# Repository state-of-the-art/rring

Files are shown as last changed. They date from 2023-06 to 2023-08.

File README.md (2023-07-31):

# RRing

Smart-Ring opensource project

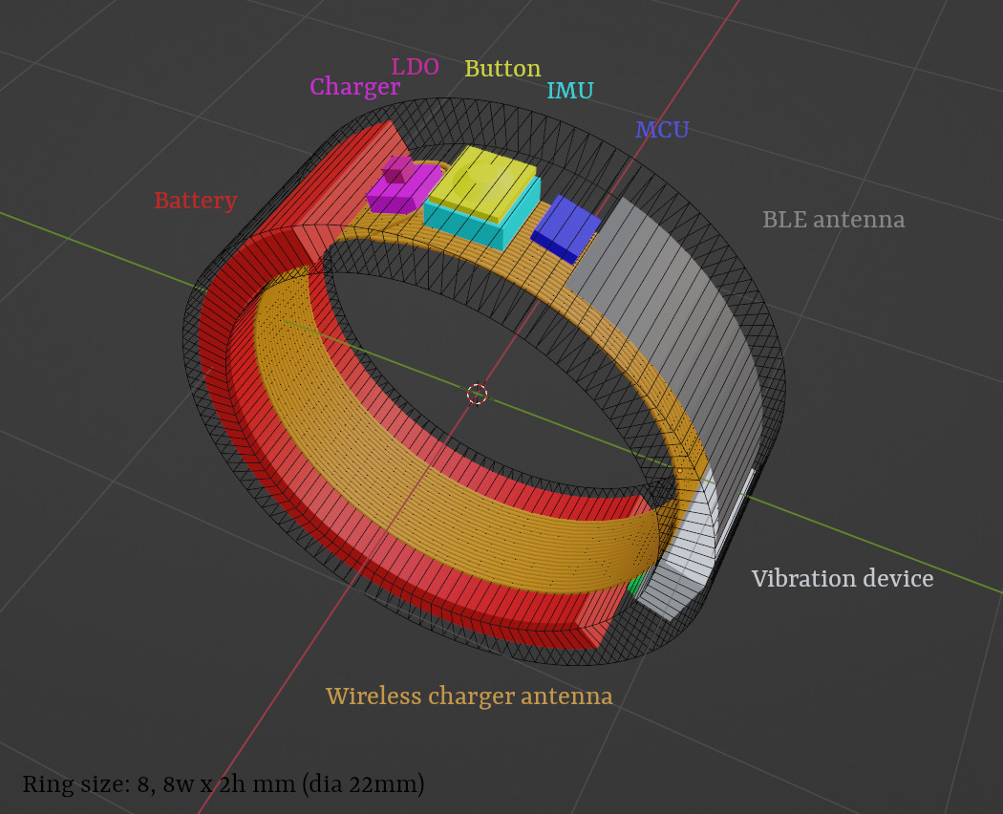
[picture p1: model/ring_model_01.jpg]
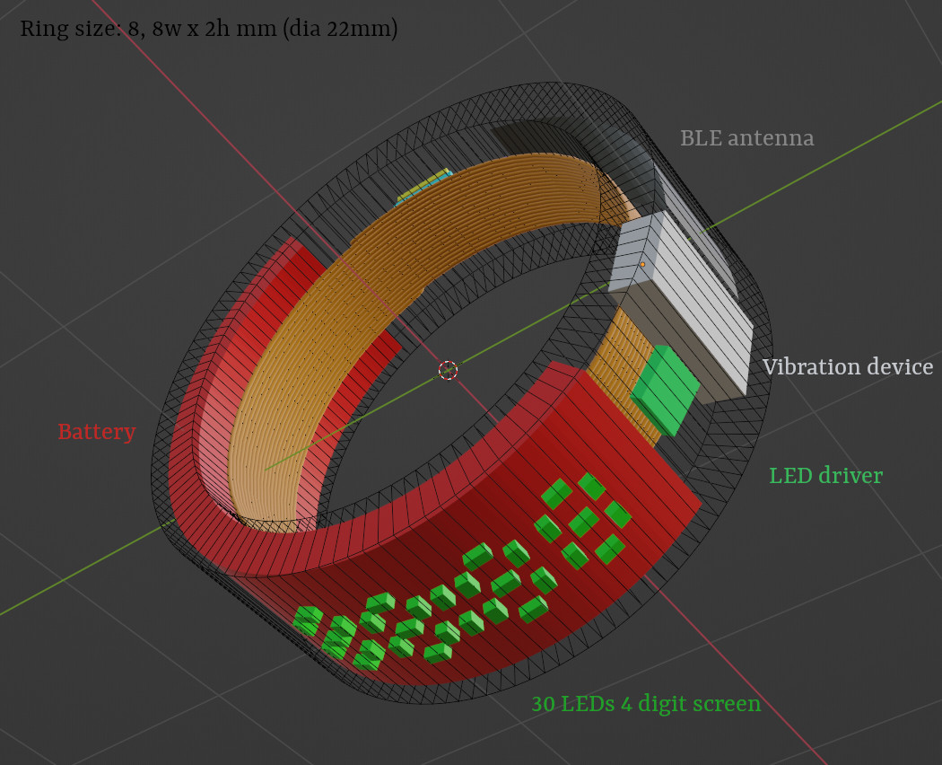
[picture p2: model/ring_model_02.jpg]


## Features

* BLE connection to smartphone
* Programmable button
* Integrated IMU for positioning in space (3d mouse)
* Show clock on little led display
* Silent vibro alarm, notifications and feedback
* Wireless charging

## BOM

* SOC:
   * MCU: DA14531-OG2 (WLCSP 17)
   * BT Antenna: ANT3216LL00R2400A (SMD Chip)
* Power:
   * Wireless charger: LTC4124 (LQFN 12)
   * Wireless charger antenna: ???
   * LDO: ADP160ACBZ-1.8-R7 (WLCSP 4)
   * Battery: ??? TODO ??? Curved, Li, ~7x33x17.7mm
* Clock display:
   * 4 digit 7 segment LED driver: TCA6418EYFPR (DSBGA 25)
   * 30 LEDs: IN-S21AT (0201)
* Control:
   * Button: KMT071NGJLHS (IP68)
   * IMU: ICM-20948 (QFN 24)
* Additional:
   * Vibro feedback: [EM custom](models/vibro_device-mk1.blend)

## Development

For PoC I used DA14531-00FXDEVKT-U (UM-B-125) - which is a small usb devboard with embedded debug
chip (uart/jtag), have spi flash to not disturb OTP ROM and safely play with firmware, just enough
to start. For sure you will need SDK for DA14531, you can easily get it on the manufacturer site.

Must read docs:
* [About devboard](https://www.renesas.com/us/en/document/mat/um-b-125-user-manual-da14531-usb-development-kit-hardware)
* [SDK6 tutorial](https://lpccs-docs.renesas.com/Tutorial_SDK6/introduction.html)
* [SDK6 peripherals tutorial](https://lpccs-docs.renesas.com/da145xx_tutorial_sdk6_peripherals/introduction.html)
* [SDK6 debugging](https://lpccs-docs.renesas.com/tutorial_da145xx_debugging_techniques/index.html)

### How to Build & Run

1. Download SDK (6.0.18.1182.1) and unpack to any directory
2. Download SmartSnippets Studio (2.0.20.4060), eclipse based IDE, and install it to the env
3. Run SmartSnippets Studio and specify the SDK - it will be used as workspace
4. Move to Exclipse IDE from welcome screen (ensure all the deps are installed)
5. Import the project as `General -> Projects from Folder or Archive` and navigate repo directory
`src/firmware/Eclipse`
6. Select DA14531 build profile and build the imported `rring` project
7. Connect USB devboard and run `Debug RAM_DA14531` to run the firmware on the chip

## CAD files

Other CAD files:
model/rring.blend
model/vibro_device-mk1.blend

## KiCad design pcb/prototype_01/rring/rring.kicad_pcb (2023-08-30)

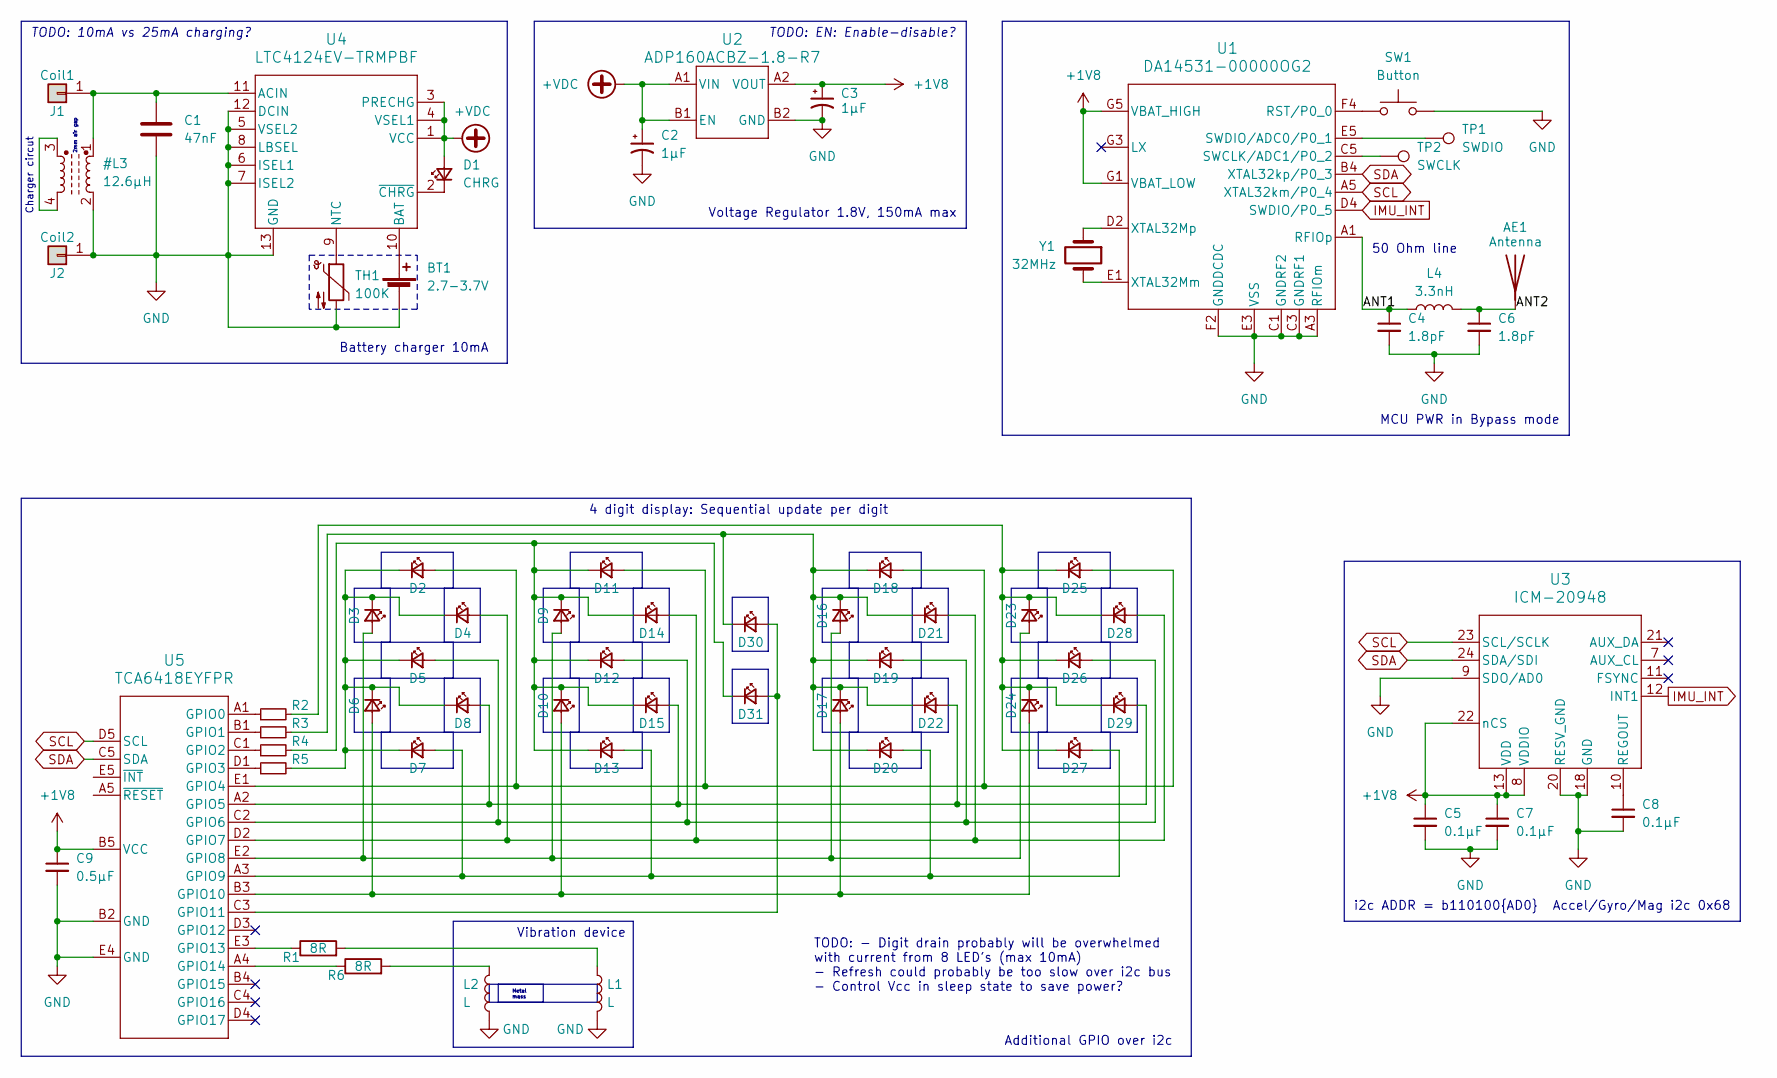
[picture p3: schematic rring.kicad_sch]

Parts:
AE1: Antenna; ANT_ANT3216_YAG
BT1: 2.7-3.7V; R_0805_2012Metric
C1: 47nF; C_0201_0603Metric
C2, C3: 1µF; C_0201_0603Metric
C4, C6: 1.8pF; C_0201_0603Metric
C5, C7, C8: 0.1µF; C_0201_0603Metric
C9: 0.5µF; C_0201_0603Metric
D1: CHRG; D_0201_0603Metric
D2, D3, D4, D5, D6, D7, D8, D9, D10, D11, D12, D13, D14, D15, D16, D17, D18, D19, D20, D21, D22, D23, D24, D25, D26, D27, D28, D29, D30, D31: DIG; D_0201_0603Metric
J1: Coil1; Conn_Pad_0.5x0.5mm
J2: Coil2; Conn_Pad_0.5x0.5mm
L1, L2: L; L_0805_2012Metric
L4: 3.3nH; L_0201_0603Metric
R1, R6: 8R; R_0201_0603Metric
R2, R3, R4, R5: R_Small; R_0201_0603Metric
SW1: Button; KMT0_push_3x2.6
TH1: 100K; R_0402_1005Metric
TP1: SWDIO; TestPoint_Pad_D0.5mm
TP2: SWCLK; TestPoint_Pad_D0.5mm
U1: DA14531-00000OG2; DA14531-00000OG2_DIL
U2: ADP160ACBZ-1.8-R7; CB_4_1_ADI
U3: ICM-20948; QFN24_3X3X0P9_IVS
U4: LTC4124EV-TRMPBF; LQFN12_ADI
U5: TCA6418EYFPR; YFP25_TEX
Y1: 32MHz; Crystal_SMD_2016-4Pin_2.0x1.6mm

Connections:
+1V8: C3.1, C5.1, C7.1, C9.1, U1.G1 (VBAT_LOW), U1.G5 (VBAT_HIGH), U2.A2 (VOUT), U3.8 (VDDIO), U3.13 (VDD), U3.22 (nCS), U5.B5 (VCC)
+VDC: C2.1, D1.2 (A), U2.A1 (VIN), U2.B1 (EN), U4.1 (VCC), U4.3 (PRECHG), U4.4 (VSEL1)
/ANT1: C4.1, L4.1, U1.A1 (RFIOp)
/ANT2: AE1.1 (A), C6.1, L4.2
IMU_INT: U1.D4 (SWDIO/P0_5), U3.12 (INT1)
unnamed: BT1.1 (+), U4.10 (BAT)
unnamed: D1.1 (K), U4.2 (~CHRG)
unnamed: D2.1 (K), D3.1 (K), D4.1 (K), D5.1 (K), D6.1 (K), D7.1 (K), D8.1 (K), R5.2
unnamed: D6.2 (A), D10.2 (A), D17.2 (A), D24.2 (A), U5.B3 (GPIO10)
unnamed: D9.1 (K), D10.1 (K), D11.1 (K), D12.1 (K), D13.1 (K), D14.1 (K), D15.1 (K), D31.1 (K), R4.2
unnamed: D2.2 (A), D11.2 (A), D18.2 (A), D25.2 (A), U5.E1 (GPIO4)
unnamed: D5.2 (A), D12.2 (A), D19.2 (A), D26.2 (A), U5.C2 (GPIO6)
unnamed: D7.2 (A), D13.2 (A), D20.2 (A), D27.2 (A), U5.A3 (GPIO9)
unnamed: D4.2 (A), D14.2 (A), D21.2 (A), D28.2 (A), U5.D2 (GPIO7)
unnamed: D8.2 (A), D15.2 (A), D22.2 (A), D29.2 (A), U5.A2 (GPIO5)
unnamed: D3.2 (A), D9.2 (A), D16.2 (A), D23.2 (A), U5.E2 (GPIO8)
unnamed: D16.1 (K), D17.1 (K), D18.1 (K), D19.1 (K), D20.1 (K), D21.1 (K), D22.1 (K), D30.1 (K), R3.2
unnamed: D23.1 (K), D24.1 (K), D25.1 (K), D26.1 (K), D27.1 (K), D28.1 (K), D29.1 (K), R2.2
unnamed: D30.2 (A), D31.2 (A), U5.C3 (GPIO11)
unnamed: L1.1, R1.2
unnamed: L2.2, R6.2
unnamed: SW1.1, U1.F4 (RST/P0_0)
unnamed: TP2.1, U1.C5 (SWCLK/ADC1/P0_2)
unnamed: TP1.1, U1.E5 (SWDIO/ADC0/P0_1)
unnamed: U1.E1 (XTAL32Mm), Y1.2
unnamed: U1.D2 (XTAL32Mp), Y1.1
unnamed: C8.1, U3.10 (REGOUT)
unnamed: TH1.1, U4.9 (NTC)
unnamed: R2.1, U5.A1 (GPIO0)
unnamed: R3.1, U5.B1 (GPIO1)
unnamed: R4.1, U5.C1 (GPIO2)
unnamed: R5.1, U5.D1 (GPIO3)
unnamed: R1.1, U5.E3 (GPIO13)
unnamed: R6.1, U5.A4 (GPIO14)
SCL: U1.A5 (XTAL32km/P0_4), U3.23 (SCL/SCLK), U5.D5 (SCL)
SDA: U1.B4 (XTAL32kp/P0_3), U3.24 (SDA/SDI), U5.C5 (SDA)

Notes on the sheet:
Additional GPIO over i2c
Metal mass
TODO: EN: Enable-disable?
i2c ADDR = b110100{AD0}
Voltage Regulator 1.8V, 150mA max
4 digit display: Sequential update per digit
50 Ohm line
Charger circut
TODO: - Digit drain probably will be overwhelmed with current from 8 LED's (max 10mA) - Refresh could probably be too slow over i2c bus - Control Vcc in sleep state to save power?
2mm air gap
Vibration device
TODO: 10mA vs 25mA charging?
Accel/Gyro/Mag i2c 0x68
MCU PWR in Bypass mode
Battery charger 10mA

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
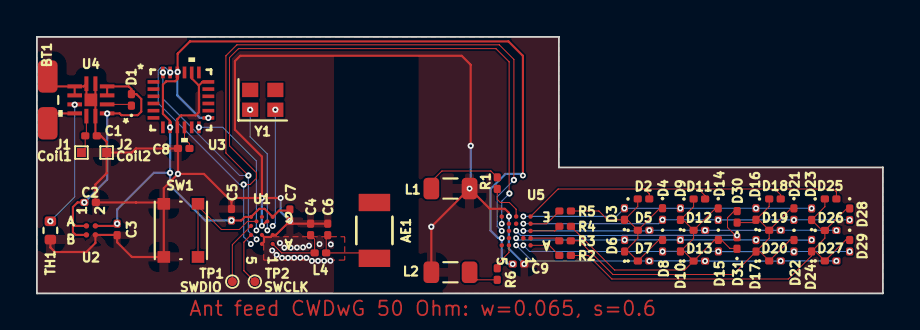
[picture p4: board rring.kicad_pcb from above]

Board: 2 copper layers, 47.0 x 14.2 mm, 63 parts (0 on the bottom side), 38 nets.

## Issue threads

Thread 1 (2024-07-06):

Were you able to complete this ring?

Cosmopal, 2024-07-06:
Hey,
The project looks very promising, I would love to colab and get this to completion.

rabits, 2024-07-06:
Hi @Cosmopal , no unfortunately I was not able to actually implement it. The complexity, as far I remember, was:
* 2.4Ghz antenna design - quite a complicated topic.
* Battery - had a talk to manufacturers and producing of such were pricey
* Vibration device design was a fail since I'm not that great in mini-physics of magnetic fields and without such vibration the ring looks incomplete.

So if you wish to try to actually build it or can somehow help with the issues - that could be a great kick for me to continue the hw & firmware development. For now it's not really needed by anyone - so I stopped development since have some pressing projects.

As far I see I can copy the antenna design of the ring I used as prototype or try to get OmniRing design: https://www.cse.psu.edu/~mkg31/projects/omniring/ , but not quite sure if that will fit... The battery for sure can be used from another cheap smart ring, but about the vibration device I'm still not sure.

Cosmopal, 2024-07-06:
I think building the ring incrementally will be more practical. We can start small and at least have a working prototype on which we can build up. It's a challenging project for me too, which is why my idea of a first version was very small - basically a counting ring that keeps the count of number of times you touched its touch sensor, and is able to transmit that info. We can modify your current design to include a touch sensor instead of the vibration motor.

Can you share some details about the two challenges you mentioned above? Let me take a stab at it.
Meanwhile, we could:
- Replace the BT sensor with NFC, which we can use for both comms and charging
- Leave vibration out of scope if it doesn't work out.

The OmniRing's paper is there, but the design, specs or program is not available. One has to fill a Google form to request info. I did try to reach out to OmniRing team, but they have not been responding.

A ring is a very potent wearable device, and I'd love to have a tinkerable open source ring.

rabits, 2024-07-07:
I think it's reasonable to build it incrementally - for sure you can remove some unnecessary parts (just do not fill the places there on the PCB). There is a physical button included in the design, because I found that touch button is not work that great - but if you need you can modify it to touch for sure.

"Replace the BT sensor with NFC" - what do you mean? Not quite sure I understand how nfc will work as a charger and what is "BT sensor".

And what kind of additional info I can provide? Not sure if you looked into the repo - there are 3d models, PCB and sample firmware (just the beginning of it), so it contains everything I have for now. And I recalled that I managed to replace the pcb antenna with solid state one, so one problem less!

Cosmopal, 2024-07-07:
Yes, I found the docs you had put in the repo. I’m still going through them. I was looking for details like:
- which battery vendors you talked to and what price range did you find?
- What exactly was the challenge with the vibration motor? Was the magnetism from it causing issues with circuit?

rabits, 2024-07-07:
* About batteries I talked to:
   * Shenzhen Ykxbattery Energy Co., Ltd., they've requested MOQ 20000pcs and sample making cost is $650.
   * Shenzhen Cowon Technology Limited and General Electronics Technology Co., Ltd., but their batteries was not "arc" type
* Vibration device - even the smallest motors are actually don't fit into the form-factor, so I thought about making a custom magnetic-induction one, where magnet mass will be moved in a chamber between 2 points back and forth hitting the walls and making vibration this way: [vibro_device-mk1.blend](https://github.com/state-of-the-art/rring/blob/main/model/vibro_device-mk1.blend). I tested a couple of implementations, but they were working not well...
   * First iteration with the small magnet (1h2d) - incorrect magnetic field:
   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
   * Second iteration was with ferromagnetic metal as mass - no pics, the mass moved around but did not made any impact and easily stuck.

nmn28, 2024-09-20:
hi guys. this is the battery that oura ring uses: 3.7V 16mAh Lithium Battery - Grepow YE160723G. its custom curved lipo.

would love to connect further

ahmetselmanerdogan, 2025-01-14:
There are deficiencies, I would like to talk about the details of the file, can you contact me?

rabits, 2025-01-14:
@ahmetselmanerdogan why not to discuss those right here? It's open conversation - nothing to hide, especially deficiencies.

ahmetselmanerdogan, 2025-01-15:
> @ahmetselmanerdogan why not to discuss those right here? It's open conversation - nothing to hide, especially deficiencies.

You are right, but how could I reach you? Can you write me on wp to meet? My number is +90 5078872959

zehaaan, 2025-05-30:
Any updates... I am all in this project...  i wanna add ai features here....

rabits, 2025-05-30:
Hi @zehaaan , unfortunately project is abandoned, because there are cheap & convenient hardware existing already and even with a way to flash your own firmware: https://github.com/atc1441/ATC_SR08_Ring/ - it's using better chip and almost as good as my project, except it doesn't have physical button (touch one) and vibromotor - but that's small things.

SirNate0, 2025-07-14:
Another open source ring: https://github.com/stawiski/open-ring

Which may have had hardware made, I'm a little unclear on that. You can follow the creator's blog [here](https://interrupt.memfault.com/blog/smart-ring-development-part-2).

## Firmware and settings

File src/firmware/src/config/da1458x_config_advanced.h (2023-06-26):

/**
 ****************************************************************************************
 *
 * @file da1458x_config_advanced.h
 *
 * @brief Advanced compile configuration file.
 *
 * Copyright (C) 2023 State of the Art LLC.
 *
 ****************************************************************************************
 */

#ifndef _DA1458X_CONFIG_ADVANCED_H_
#define _DA1458X_CONFIG_ADVANCED_H_

#include "da1458x_stack_config.h"

#if !defined (__DA14531__)

/****************************************************************************************************************/
/* Low Power clock selection.                                                                                   */
/*      -LP_CLK_XTAL32      External XTAL32K oscillator                                                         */
/*      -LP_CLK_RCX20       Internal RCX clock                                                                  */
/*      -LP_CLK_FROM_OTP    Use the selection in the corresponding field of OTP Header                          */
/*                                                                                                              */
/* NOTE: Disable CFG_XTAL16M_ADAPTIVE_SETTLING flag when RCX is chosen as the LP clock either from the OTP      */
/*       header or from the SDK.                                                                                */
/****************************************************************************************************************/
#define CFG_LP_CLK              LP_CLK_XTAL32

/****************************************************************************************************************/
/* If defined the application uses a hardcoded value for XTAL16M trimming. Should be disabled for devices       */
/* where XTAL16M is calibrated and trim value is stored in OTP.                                                 */
/* Important note. The hardcoded value is the average value of the trimming values giving the optimal results   */
/* for DA14585 DK devices. May not be applicable in other designs                                               */
/****************************************************************************************************************/
#define CFG_USE_DEFAULT_XTAL16M_TRIM_VALUE_IF_NOT_CALIBRATED

/****************************************************************************************************************/
/* Periodic wakeup period to poll GTL iface. Time in msec.                                                      */
/****************************************************************************************************************/
#define CFG_MAX_SLEEP_DURATION_PERIODIC_WAKEUP_MS                  500  // 0.5s

/****************************************************************************************************************/
/* Periodic wakeup period if GTL iface is not enabled. Time in msec.                                            */
/****************************************************************************************************************/
#define CFG_MAX_SLEEP_DURATION_EXTERNAL_WAKEUP_MS              600000  // 600s

/****************************************************************************************************************/
/* Wakeup from external processor running host application.                                                     */
/****************************************************************************************************************/
#undef CFG_EXTERNAL_WAKEUP

/****************************************************************************************************************/
/* Wakeup external processor when a message is sent to GTL                                                      */
/****************************************************************************************************************/
#undef CFG_WAKEUP_EXT_PROCESSOR
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

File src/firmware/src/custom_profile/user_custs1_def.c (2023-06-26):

/**
 ****************************************************************************************
 *
 * @file user_custs1_def.c
 *
 * @brief Custom Server 1 (CUSTS1) profile database definitions.
 *
 * Copyright (C) 2023 State of the Art LLC.
 *
 ****************************************************************************************
 */

/**
 ****************************************************************************************
 * @defgroup USER_CONFIG
 * @ingroup USER
 * @brief Custom server 1 (CUSTS1) profile database definitions.
 *
 * @{
 ****************************************************************************************
 */

/*
 * INCLUDE FILES
 ****************************************************************************************
 */

#include <stdint.h>
#include "co_utils.h"
#include "prf_types.h"
#include "attm_db_128.h"
#include "user_custs1_def.h"

/*
 * LOCAL VARIABLE DEFINITIONS
 ****************************************************************************************
 */

// Service 1 of the custom server 1
static const att_svc_desc128_t custs1_svc1                      = DEF_SVC1_UUID_128;

static const uint8_t SVC1_CTRL_POINT_UUID_128[ATT_UUID_128_LEN]       = DEF_SVC1_CTRL_POINT_UUID_128;
static const uint8_t SVC1_LED_STATE_UUID_128[ATT_UUID_128_LEN]        = DEF_SVC1_LED_STATE_UUID_128;
static const uint8_t SVC1_ADC_VAL_1_UUID_128[ATT_UUID_128_LEN]        = DEF_SVC1_ADC_VAL_1_UUID_128;
static const uint8_t SVC1_ADC_VAL_2_UUID_128[ATT_UUID_128_LEN]        = DEF_SVC1_ADC_VAL_2_UUID_128;
static const uint8_t SVC1_BUTTON_STATE_UUID_128[ATT_UUID_128_LEN]     = DEF_SVC1_BUTTON_STATE_UUID_128;
static const uint8_t SVC1_INDICATEABLE_UUID_128[ATT_UUID_128_LEN]     = DEF_SVC1_INDICATEABLE_UUID_128;
static const uint8_t SVC1_LONG_VALUE_UUID_128[ATT_UUID_128_LEN]       = DEF_SVC1_LONG_VALUE_UUID_128;

// Service 2 of the custom server 1
static const att_svc_desc128_t custs1_svc2                      = DEF_SVC2_UUID_128;

static const uint8_t SVC2_WRITE_VAL_1_UUID_128[ATT_UUID_128_LEN]      = DEF_SVC2_WRITE_VAL_1_UUID_128;
static const uint8_t SVC2_WRITE_VAL_2_UUID_128[ATT_UUID_128_LEN]      = DEF_SVC2_WRITE_VAL_2_UUID_128;

// Service 3 of the custom server 1
static const att_svc_desc128_t custs1_svc3                      = DEF_SVC3_UUID_128;

static const uint8_t SVC3_READ_VAL_1_UUID_128[ATT_UUID_128_LEN]       = DEF_SVC3_READ_VAL_1_UUID_128;
static const uint8_t SVC3_READ_VAL_2_UUID_128[ATT_UUID_128_LEN]       = DEF_SVC3_READ_VAL_2_UUID_128;
static const uint8_t SVC3_READ_VAL_3_UUID_128[ATT_UUID_128_LEN]       = DEF_SVC3_READ_VAL_3_UUID_128;

// Attribute specifications
static const uint16_t att_decl_svc       = ATT_DECL_PRIMARY_SERVICE;
static const uint16_t att_decl_char      = ATT_DECL_CHARACTERISTIC;
static const uint16_t att_desc_cfg       = ATT_DESC_CLIENT_CHAR_CFG;
static const uint16_t att_desc_user_desc = ATT_DESC_CHAR_USER_DESCRIPTION;

/*
 * GLOBAL VARIABLE DEFINITIONS
 ****************************************************************************************
 */

const uint8_t custs1_services[]  = {SVC1_IDX_SVC, SVC2_IDX_SVC, SVC3_IDX_SVC, CUSTS1_IDX_NB};
const uint8_t custs1_services_size = ARRAY_LEN(custs1_services) - 1;
const uint16_t custs1_att_max_nb = CUSTS1_IDX_NB;

/// Full CUSTS1 Database Description - Used to add attributes into the database
const struct attm_desc_128 custs1_att_db[CUSTS1_IDX_NB] =
{
    /*************************
     * Service 1 configuration
     *************************
     */

    // Service 1 Declaration
    [SVC1_IDX_SVC]                     = {(uint8_t*)&att_decl_svc, ATT_UUID_128_LEN, PERM(RD, ENABLE),
                                            sizeof(custs1_svc1), sizeof(custs1_svc1), (uint8_t*)&custs1_svc1},

    // Control Point Characteristic Declaration
    [SVC1_IDX_CONTROL_POINT_CHAR]      = {(uint8_t*)&att_decl_char, ATT_UUID_16_LEN, PERM(RD, ENABLE),
                                            0, 0, NULL},

    // Control Point Characteristic Value
    [SVC1_IDX_CONTROL_POINT_VAL]       = {SVC1_CTRL_POINT_UUID_128, ATT_UUID_128_LEN, PERM(WR, ENABLE) | PERM(WRITE_REQ, ENABLE),
                                            DEF_SVC1_CTRL_POINT_CHAR_LEN, 0, NULL},

    // Control Point Characteristic User Description
    [SVC1_IDX_CONTROL_POINT_USER_DESC] = {(uint8_t*)&att_desc_user_desc, ATT_UUID_16_LEN, PERM(RD, ENABLE),
                                            sizeof(DEF_SVC1_CONTROL_POINT_USER_DESC) - 1, sizeof(DEF_SVC1_CONTROL_POINT_USER_DESC) - 1,
                                            (uint8_t *) DEF_SVC1_CONTROL_POINT_USER_DESC},

    // LED State Characteristic Declaration
    [SVC1_IDX_LED_STATE_CHAR]          = {(uint8_t*)&att_decl_char, ATT_UUID_16_LEN, PERM(RD, ENABLE),
                                            0, 0, NULL},
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

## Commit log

2023-06-09 Added ring model
    [rring.blend]
2023-07-31 Added first and not working well vibro device & smd antenna
    [vibro_device-mk1.blend]
2023-07-31 Added schematics and initial PCB
    [rring.kicad_pcb, rring.kicad_sch]
2023-08-30 Completed the main PCB of the first prototype
    [rring.kicad_pcb, rring.kicad_sch]
